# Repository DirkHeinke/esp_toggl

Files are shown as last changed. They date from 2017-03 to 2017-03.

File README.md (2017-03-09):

# Toggl Button

A simple button for starting and stopping tasks on toggl.

Core is a ESP8266-01 connected directly to the toggl API. In this repository you can find the sourcecode for the ESP (/software) and the schematics for the board (/hardware). A PDF version of the schematics is available in the docs folder.

I used an old LED light and replaced everything inside. The USB cable is only used for powering the ESP. Any USB power adapter is good enough to run it. After first boot, the ESP creates a hotspot and asks for credentials to connect to your WiFi. On the next settings page (available via the local ip address from the ESP) you need to specify your API key, a workspace ID and a task name. The task name is always the same, but you can later rename the tasks on the toggl homepage. Until these settings are set, the button will blink yellow.

When you start a new task, the button will light up in red. The status is synced every 30s with the toggl API, so if you create a task via the app, the button will also light up.

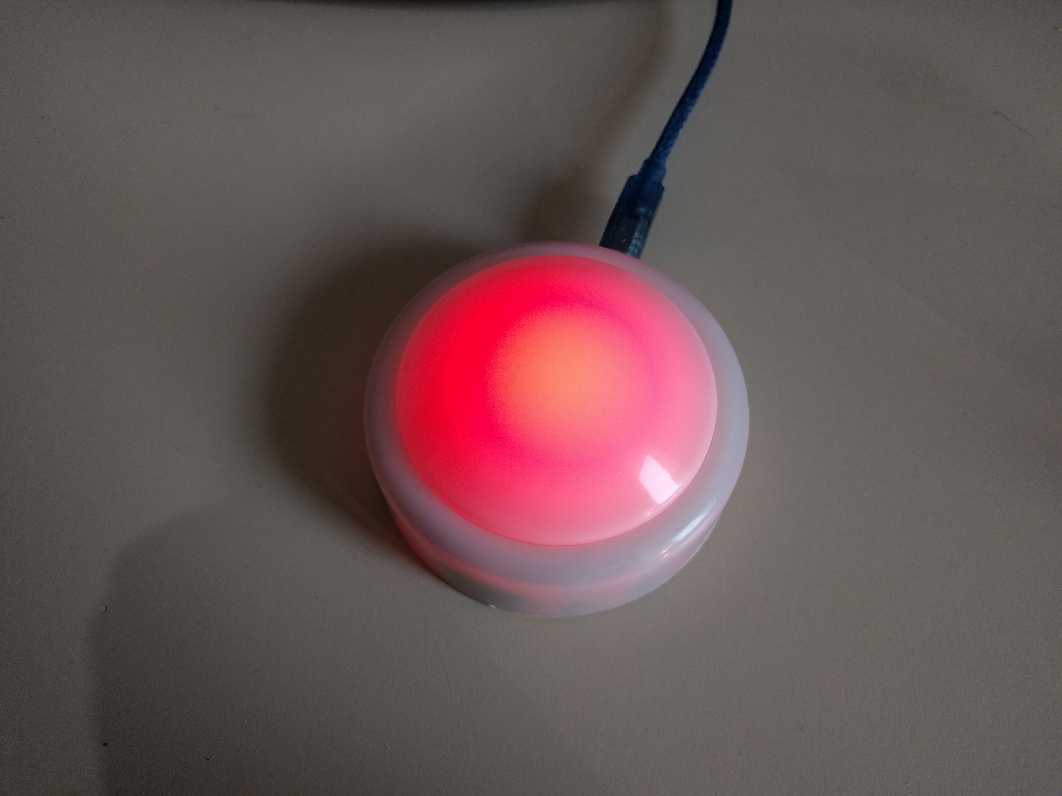
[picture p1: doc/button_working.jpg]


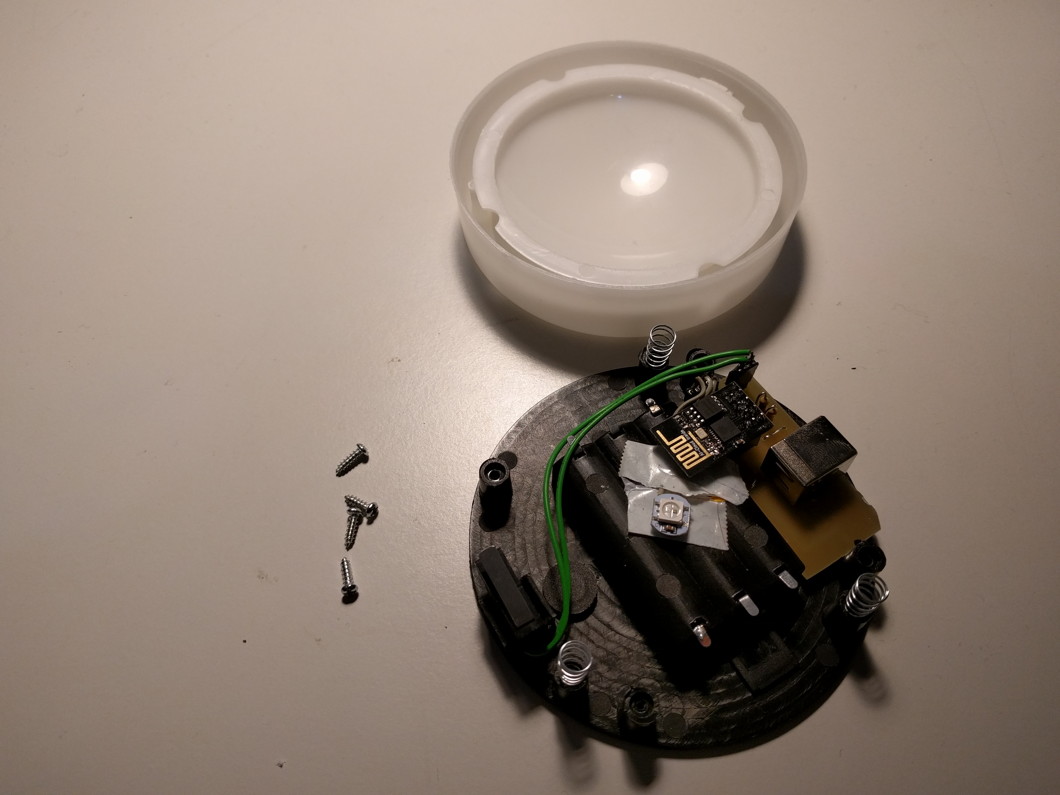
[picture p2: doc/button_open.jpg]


## UI

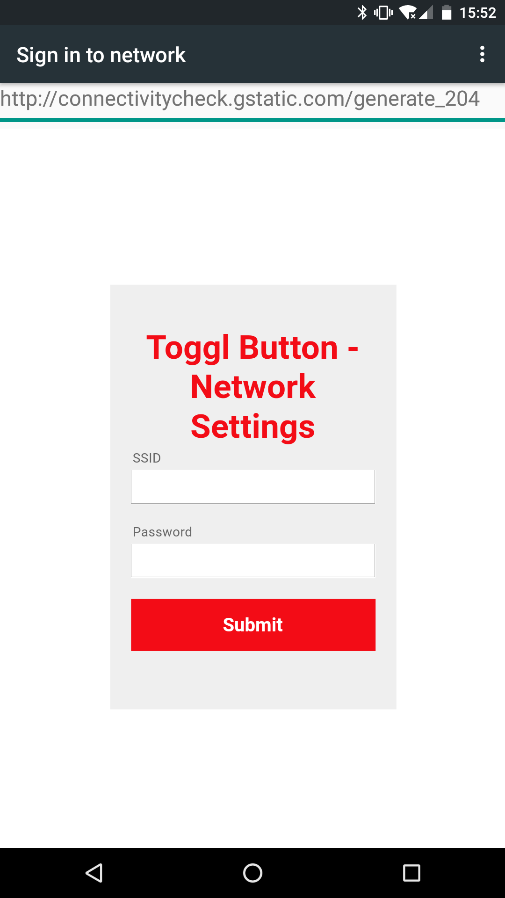
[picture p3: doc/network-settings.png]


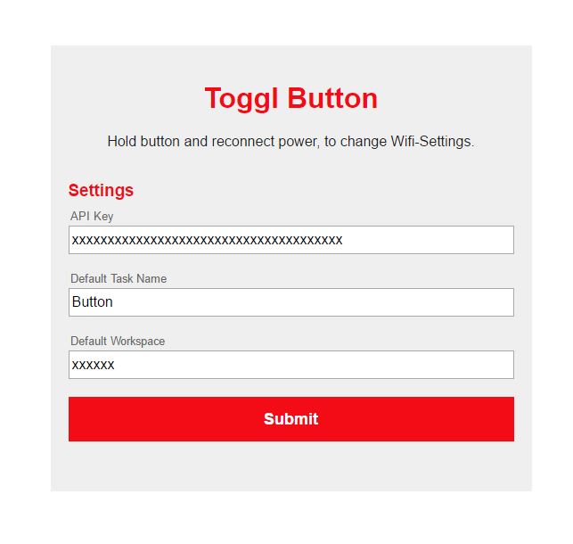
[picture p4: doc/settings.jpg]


## Hardware

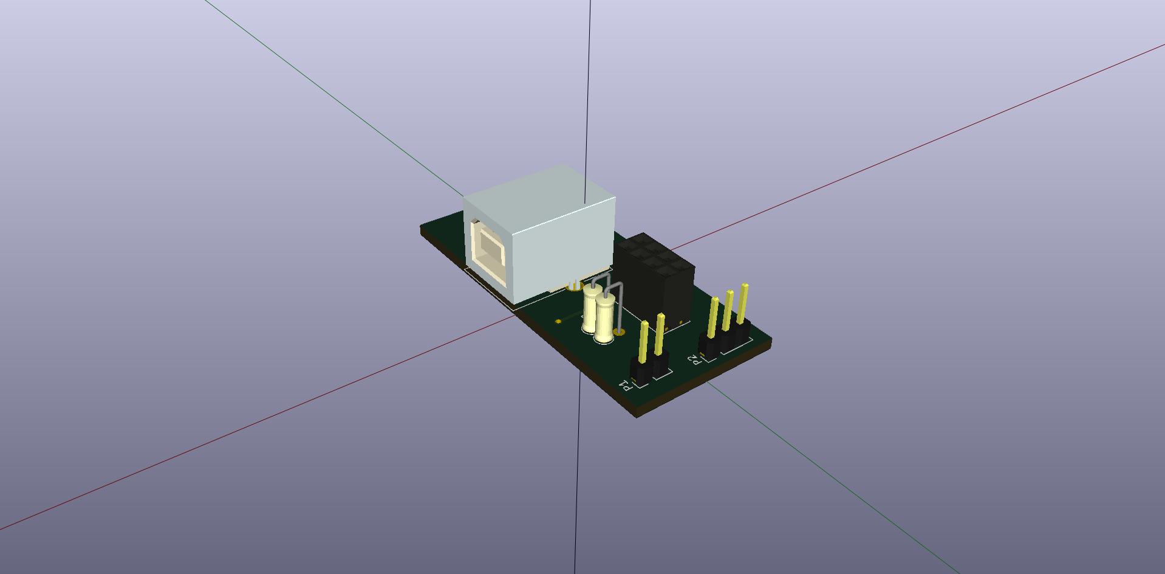
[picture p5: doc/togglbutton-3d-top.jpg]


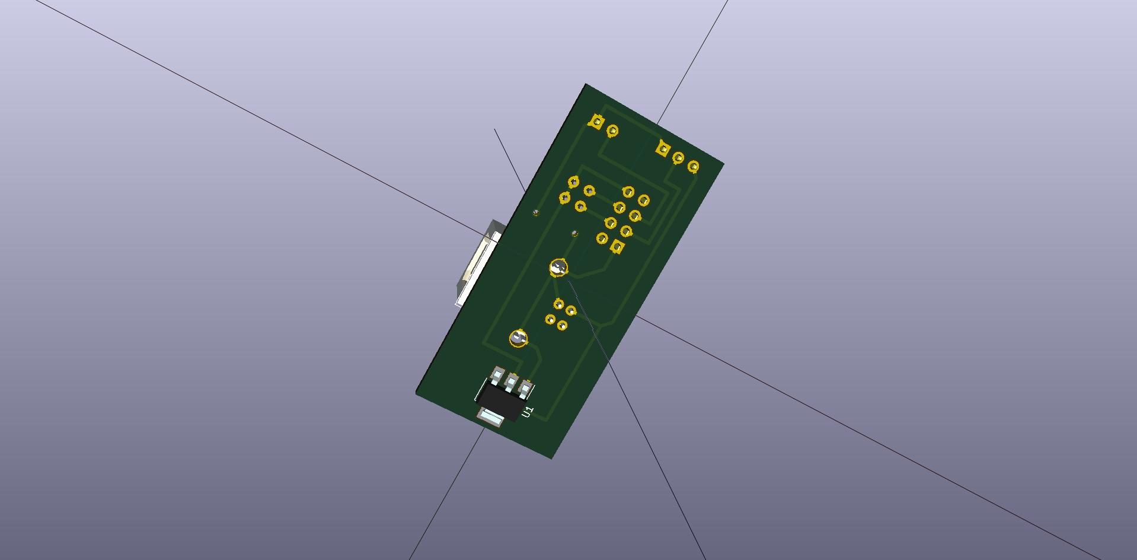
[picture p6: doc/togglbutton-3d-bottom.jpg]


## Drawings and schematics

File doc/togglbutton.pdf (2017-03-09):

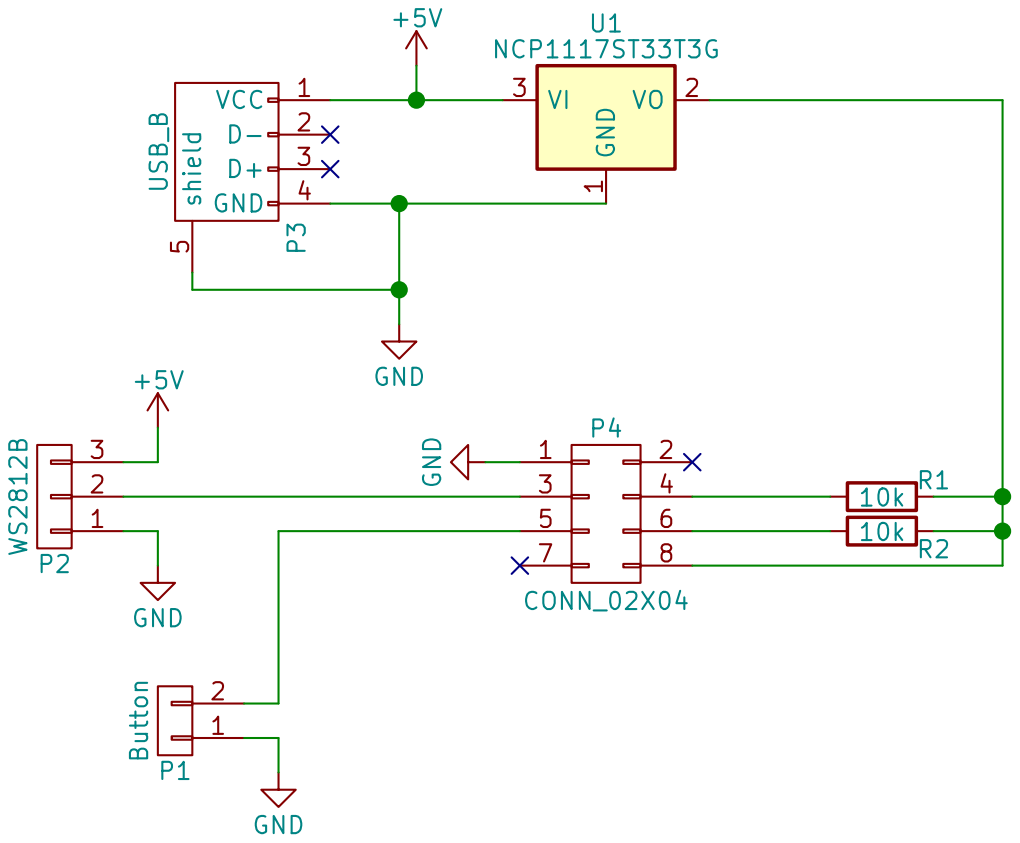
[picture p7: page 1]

File: togglbutton.sch Sheet: /
Id: 1/1 Title:

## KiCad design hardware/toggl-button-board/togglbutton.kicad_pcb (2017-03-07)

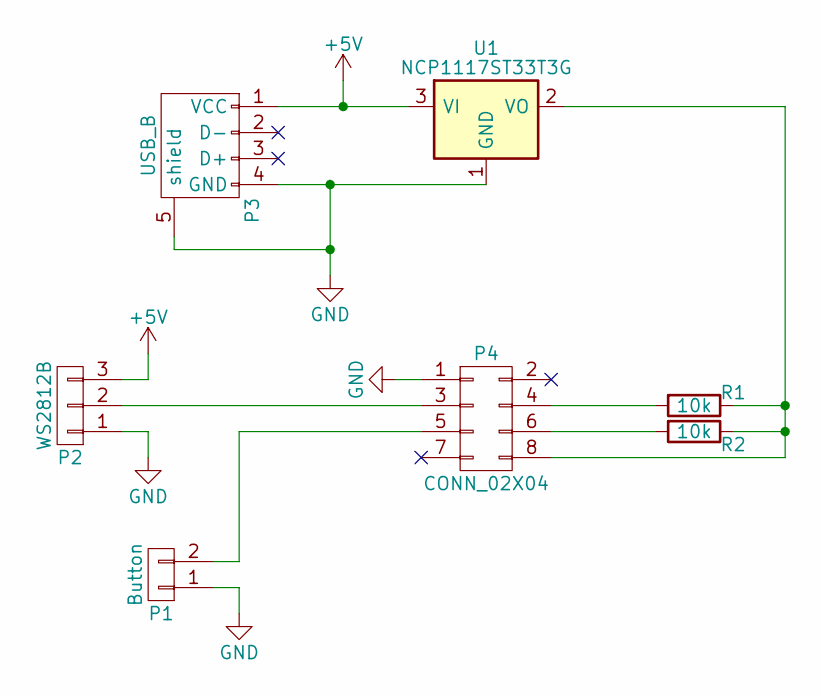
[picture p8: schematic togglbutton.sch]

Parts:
P1: Button; Pin_Header_Straight_1x02_Pitch2.54mm
P2: WS2812B; Pin_Header_Straight_1x03_Pitch2.54mm
P3: USB_B
P4: CONN_02X04; Socket_Strip_Straight_2x04_Pitch2.54mm
R1, R2: 10k; R_Axial_DIN0207_L6.3mm_D2.5mm_P2.54mm_Vertical
U1: NCP1117ST33T3G; SOT-223

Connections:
+5V: P2.3, P3.1 (VCC), U1.3 (VI)
GND: P1.1, P2.1, P3.4 (GND), P3.5 (shield), P4.1, U1.1 (GND)
unnamed: P1.2, P4.5
unnamed: P2.2, P4.3
unnamed: P4.4, R1.2
unnamed: P4.6, R2.2
unnamed: P4.8, R1.1, R2.1, U1.2 (VO)

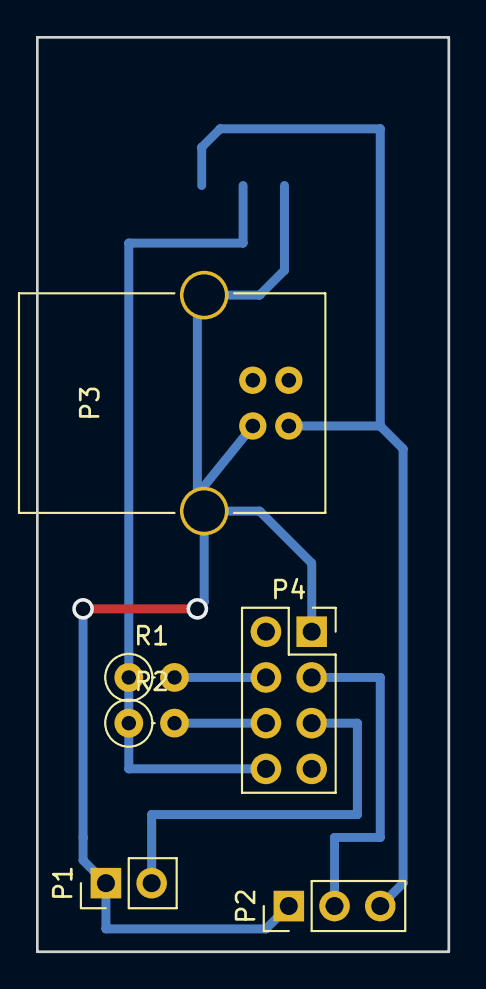
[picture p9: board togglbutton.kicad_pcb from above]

Board: 2 copper layers, 22.9 x 50.8 mm, 7 parts (1 on the bottom side), 7 nets.

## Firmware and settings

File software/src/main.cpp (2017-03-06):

#include <Arduino.h>
#include <ESP8266WiFi.h>
#include <WiFiClientSecure.h>
#include <Adafruit_NeoPixel.h>
#include <Ticker.h>
#include <ESP8266WebServer.h>
//#include <WiFiManager.h>
#include <base64.h>
#include <ArduinoHttpClient.h>
#include <DNSServer.h>


#include "config.hpp"
#include "microHTTP.h"

#define DEBUG
#define CONNECTION_TIMEOUT 10000

#define GPIO0 0 //D3
#define GPIO2 2 //D4

const int ButtonPin = GPIO0;
int buttonState = 0;
Adafruit_NeoPixel strip = Adafruit_NeoPixel(1, GPIO2, NEO_GRB + NEO_KHZ800);
Ticker checkStatus;
bool queuedCheckToggle = true;
String runningId = "0";
ESP8266WebServer server(80);
bool configured = false;
bool newNetworkSettings = false;
bool newNetworkFound = false;
bool buttonPressed = false;

String newssid;
String newpassword;

Settings conf;
WiFiClientSecure wcs;

bool startNewEntry();
String getCurrentId();
void checkToggl();
void queueCheckToggl();
void stopWork(String);
void configPage();
void startAP();
void handleButtonPress();

void setup()
{
    Serial.begin(115200);
    Serial.println("");
    delay(1000);

    pinMode(ButtonPin, INPUT_PULLUP);
    if(digitalRead(ButtonPin) == 0) {
        clearConfig();
        Serial.println("Removed Settings");
    }


    if(readConfig(conf)) {
        // config found, try to connect
        Serial.println("Trying to connect to: " + String(conf.ssid) + " with " + String(conf.password));
        if(conf.taskname1 && conf.apikey && conf.wid1) {
            configured = true;
        }
        WiFi.disconnect();
        WiFi.begin(conf.ssid, conf.password);

        unsigned long timeoutBegin = millis();
        bool timeout = false;
        while(WiFi.status() != WL_CONNECTED) {
            if(( millis() - timeoutBegin) > CONNECTION_TIMEOUT) {
                timeout = true;
                Serial.println("Connection failed");
                break;
            }
            delay(100);
        }

        if(timeout) {
            // start AP
            startAP();
        }

        // connected

    } else {
        // no config found, start AP

        // start AP
        startAP();
    }



    Serial.print("Connected. IP: ");
    Serial.println(WiFi.localIP());

    server.on("/", configPage);
    server.begin();

    strip.begin();
    strip.setPixelColor(0, 0, 255, 0);
    strip.show();
    checkStatus.attach(30, queueCheckToggl);

    attachInterrupt(ButtonPin, handleButtonPress, FALLING);

}

void loop()
{
    if(buttonPressed) {
        Serial.println("Pressed");
        if(runningId != "0") {
            Serial.println("Stop working");
            stopWork(runningId);
        } else {
            Serial.println("Start working");
            startNewEntry();
        }
        buttonPressed = false;

    }

    if(queuedCheckToggle) {
        checkToggl();
        queuedCheckToggle = false;
    }

    if(!configured) {
        if((int)(millis() / 1000) % 2 == 0) {
            strip.setPixelColor(0, 255, 255, 0);
            strip.show();
        } else {
            strip.setPixelColor(0, 0, 0, 0);
            strip.show();
        }

    }

    server.handleClient();
}

void handleButtonPress() {
    buttonPressed = true;
}


void handleConfigPage() {
    const String wifiConfigPage = ""
          "<html>"
              "<head>"
                  "<title>Toggl.com Button</title>"
                  "<style>"
                      "body {"
                      "background-color:#fff;font-family:'Arial';display:flex;align-items:center;justify-content:center;height:100vh;color:#222"
                      "}"
                      ".wrapper {"
                      "background-color:#efefef;width:50%;padding:20px;max-width:500px;"
                      "}"
                      ".font-color {color: #f30c16;}"
                      ".bg-color {background-color: #f30c16;}"
                      ".text-center {text-align:center;}"
                      ".flex-column {display:flex;flex-direction:column;}"
                      "h1 {margin-bottom:5px;}"
                      "h3 {margin-bottom:10px}"
                      ".input-container {margin-bottom:20px}"
                      ".input-container label {"
                      "color:#666;margin-bottom:3px;font-size:80%;padding-left:2px;"
                      "}"
                      ".input-container input {"
                      "margin:0;padding:5px 2px;font-size:16px;"
                      "}"
                      "input[type=\"submit\"] {"
                      "border:none;height:50px;color:white;font-size:18px;font-weight:bold;margin-bottom:20px;transition: background-color .3s ease;"
                      "}"
                      "input[type=\"submit\"]:hover {"
                      "cursor: pointer;background-color: #d70a14;"
                      "}"
                  "</style>"
              "</head>"
              "<body>"
                  "<div class=\"wrapper flex-column\">"
                      "<h1 class=\"font-color text-center\">Toggl Button - Network Settings</h1>"
                      "<div>"
                          "<form class=\"pure-form pure-form-stacked flex-column\">"
                              "<div class=\"input-container flex-column\">"
                                  "<label for='ssid'>SSID</label>"
                                  "<input type='text' id='ssid' name='ssid' required />"
                              "</div>"
                              "<div class=\"input-container flex-column\">"
                                  "<label for='password'>Password</label>"
                                  "<input type='text' id='password' name='password' required />"
                              "</div>"
                              "<input class=\"pure-button pure-button-primary bg-color\" type='submit' value='Submit'>"
                          "</form>"
                      "</div>"
                  "</div>"
              "</body>"
          "</html>";

    newssid = server.arg("ssid");
    newpassword = server.arg("password");

    if(newssid != "" && newpassword != "") {
        Serial.println("Trying to connect to: " + String(newssid) + " with " + String(newpassword));
        server.send(200, "text/html", "Trying to connect to new network.");

        newNetworkSettings = true;
    } else {
        server.send(200, "text/html", wifiConfigPage);

        newNetworkSettings = false;
    }

}

void startAP() {
    Serial.println("Start AP");

    IPAddress apIP(192, 168, 1, 1);
    WiFi.softAPConfig(apIP, apIP, IPAddress(255, 255, 255, 0));


    DNSServer dnss;
    dnss.start(53, "*", apIP);

    server.onNotFound(handleConfigPage);
    server.begin();

    while(!newNetworkFound) {
        WiFi.mode(WIFI_AP);
        WiFi.softAP("TogglButton", "thebutton");

        Serial.print("Soft-AP IP address = ");
        Serial.println(WiFi.softAPIP());

        while (!newNetworkSettings) {
            dnss.processNextRequest();
            server.handleClient();
        }

        newNetworkSettings = false;

        WiFi.mode(WIFI_STA);
        WiFi.begin(newssid.c_str(), newpassword.c_str());

        unsigned long timeoutBegin = millis();
        bool timeout = false;
        while(WiFi.status() != WL_CONNECTED) {
            if(( millis() - timeoutBegin) > CONNECTION_TIMEOUT) {
                timeout = true;
                Serial.println("Timeout!");
                break;
            }

            delay(100);
        }

        if(!timeout) {
            // Connected
            Serial.println("Connected!");
            newNetworkFound = true;
        } else {
            // Not connectable
            Serial.println("Error!");
            WiFi.disconnect();
        }

    }

    server.stop();

    Serial.println("Stop AP");
    WiFi.softAPdisconnect();
    strlcpy(conf.password, newpassword.c_str(), sizeof(conf.password));
    strlcpy(conf.ssid, newssid.c_str(), sizeof(conf.ssid));
    writeConfig(conf);

}

void queueCheckToggl() {
    queuedCheckToggle = true;
}

void checkToggl() {
    Serial.println("Checking Toggl");
    runningId = getCurrentId();
    if(runningId != "0") {
        strip.setPixelColor(0, 255, 0, 0);
        strip.show();
    } else {
        strip.setPixelColor(0, 0, 0, 0);
        strip.show();
    }
}

void configPage() {

    for (int i = 0; i < server.args(); i++ ) {
      if (server.argName(i) == "apikey" && server.arg(i) != "") strlcpy(conf.apikey, server.arg(i).c_str(), sizeof(conf.apikey));
      if (server.argName(i) == "taskname" && server.arg(i) != "") strlcpy(conf.taskname1, server.arg(i).c_str(), sizeof(conf.taskname1));
      if (server.argName(i) == "wid" && server.arg(i) != "") strlcpy(conf.wid1, server.arg(i).c_str(), sizeof(conf.wid1));
    }

    if(strlen(conf.apikey) > 0 && strlen(conf.taskname1) > 0 && strlen(conf.wid1) > 0) {
        configured = true;
        writeConfig(conf);
        Serial.println("Configuration saved");
        checkToggl();
    }

    String content = String("") +
            "<html>"
              "<head>"
                "<title>Toggl.com Button</title>"
                "<style>"
                  "body {"
                    "background-color:#fff;font-family:'Arial';display:flex;align-items:center;justify-content:center;height:100vh;color:#222"
                  "}"
                  ".wrapper {"
                    "background-color:#efefef;width:50%;padding:20px;max-width:500px;"
                  "}"
                  ".font-color {color: #f30c16;}"
                  ".bg-color {background-color: #f30c16;}"
                  ".text-center {text-align:center;}"
                  ".flex-column {display:flex;flex-direction:column;}"
                  "h1 {margin-bottom:5px;}"
                  "h3 {margin-bottom:10px}"
                  ".input-container {margin-bottom:20px}"
                  ".input-container label {"
                    "color:#666;margin-bottom:3px;font-size:80%;padding-left:2px;"
                  "}"
                  ".input-container input {"
                    "margin:0;padding:5px 2px;font-size:16px;"
                  "}"
                  "input[type=\"submit\"] {"
                    "border:none;height:50px;color:white;font-size:18px;font-weight:bold;margin-bottom:20px;transition: background-color .3s ease;"
                  "}"
                  "input[type=\"submit\"]:hover {"
                    "cursor: pointer;background-color: #d70a14;"
                  "}"
                "</style>"
              "</head>"
              "<body>"
                "<div class=\"wrapper flex-column\">"
                  "<h1 class=\"font-color text-center\">Toggl Button</h1>"
                  "<p class=\"text-center\">Hold button and reconnect power, to change Wifi-Settings.</p>"
                  "<div>"
                      "<h3 class=\"font-color\">Settings</h3>"
                      "<form class=\"pure-form pure-form-stacked flex-column\">"
                        "<div class=\"input-container flex-column\">"
                          "<label for='apikey'>API Key</label>"
                          "<input type='text' id='apikey' name='apikey' value='" +
                          String(conf.apikey) +
                          "' required />"
                        "</div>"
                        "<div class=\"input-container flex-column\">"
                          "<label for='taskname'>Default Task Name</label>"
                          "<input type='text' id='taskname' name='taskname' value='" +
                          String(conf.taskname1) +
                          "' required />"
                        "</div>"
                        "<div class=\"input-container flex-column\">"
                          "<label for='wid'>Default Workspace</label>"
                          "<input type='text' id='wid' name='wid' value='" +
                          String(conf.wid1) +
                          "' required>"
                        "</div>"
                        "<input class=\"pure-button pure-button-primary bg-color\" type='submit' value='Submit'>"
                      "</form>"
                  "</div>"
                "</div>"
              "</body>"
            "</html>";

//    Serial.println(content);

    server.send(200, "text/html", content);


}

bool startNewEntry() {

    String content = "{\"time_entry\":{\"description\":\"";
    content += conf.taskname1;
    content += "\",\"wid\":";
    content += conf.wid1;
    content += ",\"created_with\":\"Arduino\"}}";

    microHTTP mhs = microHTTP(wcs);
    httpResponse resp = mhs.post("www.toggl.com", 443, "/api/v8/time_entries/start", content, "application/json", "96e9a83a29b10059b0604991286dfe7c", "api_token");


    String respBody = resp.body;

    int idIndex = respBody.indexOf("\"id\"");
    int kommaIndex = respBody.indexOf(",", idIndex);
    if(idIndex > 0) {
        runningId = respBody.substring(idIndex + 5, kommaIndex);
        Serial.println("Found taskid:");
        Serial.println(runningId);
        strip.setPixelColor(0, 255, 0, 0);
        strip.show();
    } else {
        Serial.println("No taskid found. Something went wrong!");
    }

}

String getCurrentId() {
    microHTTP mh = microHTTP(wcs);
    httpResponse resp = mh.get("www.toggl.com", 443, "/api/v8/time_entries/current", "96e9a83a29b10059b0604991286dfe7c", "api_token");

    String respBody = resp.body;

    Serial.println(respBody);

    int idIndex = respBody.indexOf("\"id\"");
    int kommaIndex = respBody.indexOf(",", idIndex);

    if(idIndex > 0) {
        String taskId = respBody.substring(idIndex + 5, kommaIndex);
        Serial.println("Found taskid:");
        Serial.println(taskId);
        return taskId;
    } else {
        Serial.println("No taskid found. You are not working");
        return "0";
    }
}

void stopWork(String currentId) {
    microHTTP mh = microHTTP(wcs);
    httpResponse resp = mh.put("www.toggl.com", 443, "/api/v8/time_entries/" + currentId + "/stop", "", "application/json", "96e9a83a29b10059b0604991286dfe7c", "api_token");

    String respBody = resp.body;
    if(resp.status == 200) {
        strip.setPixelColor(0, 0, 0, 0);
        runningId = "0";
        strip.show();
    } else {
        strip.setPixelColor(0, 255, 0, 0);
        strip.show();
    }
}

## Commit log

2016-11-24 Fix displaying of text in input fields
    [main.cpp]
2017-03-06 Use interrupt
2017-03-06 Fix bouncing of interrupt and use response of api call as runningId
    [main.cpp]
2017-03-07 Add pcb
    [togglbutton.kicad_pcb, togglbutton.sch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]
